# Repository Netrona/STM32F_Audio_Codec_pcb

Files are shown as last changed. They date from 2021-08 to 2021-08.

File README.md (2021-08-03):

# STM32F+Audio Codec PCB Design Project

## Description 

This project is designed to interface STM32F405 with the audio codec WM8731. The board supports the development of audio applications. 

### STM32F4 Pinout selection 

I used STM32CubeMX software to configure STM32F405RGT6 MCU chip. The used connections are:

• USART2

• I2S2

• I2C1

• USB_FS 

STM32F4 Pinout selection

## Schematic Design

Schematic Design

## PCB Design

### Full tracks overveiw 

Full tracks overveiw

### Tracks with filled zones overveiw 

Tracks with filled zones overveiw

### 3D overview 

#### Top veiw 

3D overview top veiw

#### Bottom veiw 

3D overview bottom veiw

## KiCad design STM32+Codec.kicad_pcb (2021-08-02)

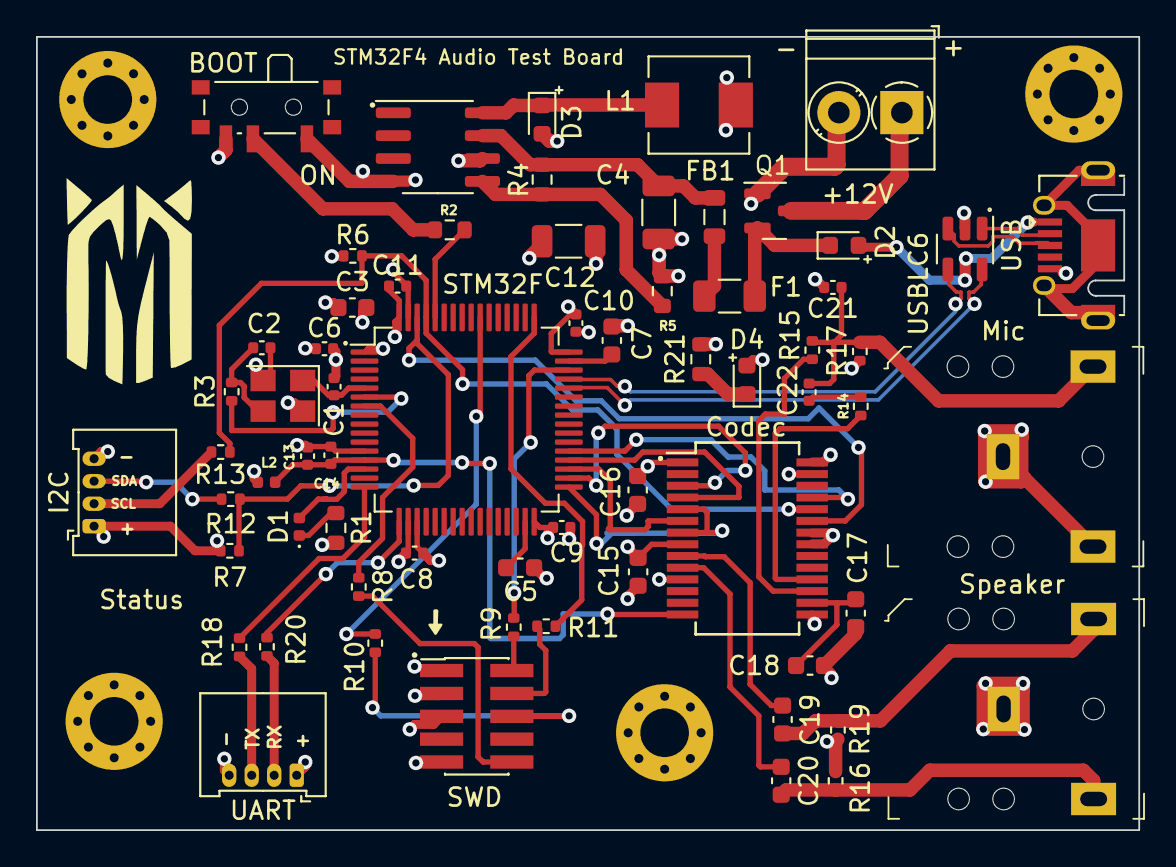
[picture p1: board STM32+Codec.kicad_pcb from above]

Board: 4 copper layers, 61.2 x 44.1 mm, 69 parts (0 on the bottom side), 54 nets.

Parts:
+12V: Power; TerminalBlock_Phoenix_PT-1,5-2-3.5-H_1x02_P3.50mm_Horizontal
BOOT: SW_SPDT; SW_SPDT_PCM12
C1, C2: 12p; C_0402_1005Metric
C3: 4u7; C_0603_1608Metric
C4: 68u; C_1206_3216Metric
C5, C7: 2u2; C_0603_1608Metric
C6, C8, C9, C10, C11: 100n; C_0402_1005Metric
C12: 120u; C_1206_3216Metric
C13: 1u; C_0402_1005Metric
C14: 10n; C_0402_1005Metric
C15, C16, C18: 0.1u; C_0603_1608Metric
C17: 10u; C_0603_1608Metric
C19, C20: 330u; C_0603_1608Metric
C21, C22: 1n; C_0402_1005Metric
Codec: WM8731SEDS; SSOP-28_5.3x10.2mm_P0.65mm
D1: LED; LED_0402_1005Metric
D2, D3: 1N5817; D_0603_1608Metric
D4: LED; LED_0603_1608Metric
F1: 250mA; Fuse_1206_3216Metric
FB1: 600 @ 600MHz; L_0805_2012Metric
H1, H2, H3, H4: MH; MountingHole_2.7mm_Pad_Via
I2C: Conn_01x04; Molex_PicoBlade_53048-0410_1x04_P1.25mm_Horizontal
L1: 47u; L_Sunlord_MWSA0518_5.4x5.2mm
L2: 39n; L_0402_1005Metric
Mic: SJ1-3523N; Headphone_Jack_3.5mm_SJ1-3523N
Q1: AO3401A; SOT-23
R1, R21: 1k5; R_0603_1608Metric
R2: 10K; R_0603_1608Metric
R3: 45; R_0402_1005Metric
R4: 100k; R_0603_1608Metric
R5: 68k; R_0603_1608Metric
R6, R7: 2.2k; R_0402_1005Metric
R8, R9, R10, R11, R12, R13, R18, R20: 22; R_0402_1005Metric
R14: 330; R_0402_1005Metric
R15: 680; R_0402_1005Metric
R16, R17, R19: 47k; R_0402_1005Metric
STM32F: STM32F405RGTx; LQFP-64_10x10mm_P0.5mm
SWD: SWD; PinHeader_2x05_P1.27mm_Vertical_SMD
Speaker: SJ1-3523N; Headphone_Jack_3.5mm_SJ1-3523N
U2: LM2594HVM-3.3; SOIC-8_3.9x4.9mm_P1.27mm
UART: Conn_01x04; Molex_PicoBlade_53048-0410_1x04_P1.25mm_Horizontal
USB: USB_B_Mini; USB_Micro-AB_Molex_47590-0001
USBLC6: USBLC6-2SC6; SOT-23-6
Y1: 16MHz; Crystal_SMD_3225-4Pin_3.2x2.5mm

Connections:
+3.3VA: C13.1, C14.1, Codec.14 (AVDD), L2.2, STM32F.13 (VDDA)
+5V: D2.2 (A), USB.1 (VBUS), USBLC6.5 (VBUS)
+12V: +12V.1, Q1.3 (D)
BOOT0: R2.2, STM32F.60 (BOOT0)
DBVDD: BOOT.1 (A), C3.1, C6.1, C8.1, C9.1, C10.1, C11.1, C12.1, C15.1, C16.1, Codec.1 (DBVDD), Codec.8 (HPVDD), Codec.27 (DCVDD), D4.2 (A), I2C.1, L1.2, L2.1, R6.1, R7.1, STM32F.1 (VBAT), STM32F.19 (VDD), STM32F.32 (VDD), STM32F.48 (VDD), STM32F.64 (VDD), SWD.1, U2.4 (FB), UART.1
GND: +12V.2, BOOT.3 (C), C1.2, C2.2, C3.2, C4.2, C5.2, C6.2, C7.2, C8.2, C9.2, C10.2, C11.2, C12.2, C13.2, C14.2, C15.2, C16.2, C17.2, C18.2, C21.2, Codec.11 (HPGND), Codec.15 (AGND), Codec.21 (MODE), Codec.22 (~CSB), Codec.28 (DGND), D3.2 (A), H1.1, H2.1, H3.1, H4.1, I2C.4, Mic.1 (S), Mic.2 (T), Q1.1 (G), R1.2, R5.2, R16.2, R17.2, R19.2, R21.2, STM32F.12 (VSSA), STM32F.18 (VSS), STM32F.63 (VSS), SWD.3, SWD.5, SWD.9, Speaker.1 (S), U2.6 (GND), UART.4, USB.5 (GND), USBLC6.2 (GND), Y1.2, Y1.4
HSE_IN: C1.1, STM32F.5 (PH0), Y1.1
HSE_OUT: R3.2, STM32F.6 (PH1)
I2C_SCL: Codec.24 (SCLK), R6.2, R13.1, STM32F.61 (PB8)
I2C_SDA: Codec.23 (SDIN), R7.2, R12.1, STM32F.62 (PB9)
I2S_LRCK: Codec.5 (DACLRC), Codec.7 (ADCLRC), STM32F.33 (PB12)
I2S_MCLK: Codec.25 (XTI/MCLK), STM32F.37 (PC6)
I2S_SCLK: Codec.3 (BCLK), STM32F.34 (PB13)
I2S_SDI: Codec.6 (ADCDAT), STM32F.35 (PB14)
I2S_SDO: Codec.4 (DACDAT), STM32F.36 (PB15)
LED_STATUS: D1.2 (A), STM32F.14 (PA0)
LHPO: C19.1, Codec.9 (LHPOUT)
MICBIAS: Codec.17 (MICBIAS), R15.1
MICIN: Codec.18 (MICIN), R14.1
NRST: R8.1, STM32F.7 (NRST)
unnamed: C2.1, R3.1, Y1.3
unnamed: C4.1, FB1.2, R4.1, U2.7 (VIN)
unnamed: C5.1, STM32F.31 (VCAP_1)
unnamed: C7.1, STM32F.47 (VCAP_2)
unnamed: C17.1, C18.1, Codec.16 (VMID)
unnamed: C19.2, R19.1, Speaker.3 (R)
unnamed: C20.2, R16.1, Speaker.2 (T)
unnamed: C21.1, C22.2, Mic.3 (R), R15.2, R17.1
unnamed: C22.1, R14.2
unnamed: D1.1 (K), R1.1
unnamed: D2.1 (K), F1.1, Q1.2 (S)
unnamed: D4.1 (K), R21.1
unnamed: F1.2, FB1.1
unnamed: R9.1, SWD.2
unnamed: R11.2, SWD.4
unnamed: R10.2, SWD.6
unnamed: R8.2, SWD.10
unnamed: I2C.2, R13.2
unnamed: I2C.3, R12.2
unnamed: R20.2, UART.2
unnamed: R18.2, UART.3
unnamed: D3.1 (K), L1.1, U2.8 (OUT)
unnamed: BOOT.2 (B), R2.1
unnamed: R4.2, R5.1, U2.5 (~ON/OFF)
RHPO: C20.1, Codec.10 (RHPOUT)
RXD: R20.1, STM32F.17 (PA3)
SWCLK: R11.1, STM32F.49 (PA14)
SWDIO: R9.2, STM32F.46 (PA13)
SWO: R10.1, STM32F.55 (PB3)
TXD: R18.1, STM32F.16 (PA2)
USB_CONN_D+: USB.3 (D+), USBLC6.3 (I/O2)
USB_CONN_D-: USB.2 (D-), USBLC6.1 (I/O1)
USB_D+: STM32F.45 (PA12), USBLC6.4 (I/O2)
USB_D-: STM32F.44 (PA11), USBLC6.6 (I/O1)
